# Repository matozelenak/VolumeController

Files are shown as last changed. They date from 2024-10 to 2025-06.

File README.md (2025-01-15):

# Hardvérový ovládač hlasitostí jednotlivých aplikácií bežiacich na PC

## Obsah

- [Softvér](#softvér)
- [3D tlač](#3d-tlač)
- [Zoznam súčiastok](#zoznam-súčiastok)
- [Zapojenie](#zapojenie)
- [Zloženie](#zloženie)
- [Výsledok](#výsledok)

## Softvér

- [Arduino kód](arduino/README.md)
- [Softvér na Windows](windows/README.md)
- [Softvér na Linux](linux/README.md)
- [GUI](gui/README.md)

## 3D tlač

Treba vytlačiť:
- krabičku ([controller_case](3d_models/controller_case.stl))
- predný panel ([controller_front_panel](3d_models/controller_front_panel.stl))
- zadné krytky na ledky (6x) ([led_cover](3d_models/led_cover.stl))
- všetky súbory logo_*.stl (odporúčam tlačiť na veľmi pomalej rýchlosti, cca 10mm/s)
- držiak na Arduino ([nano_holder_v2](3d_models/nano_holder_v2.stl))

Držiak na Arduino Nano pochádza z [Thingiverse](https://www.thingiverse.com/thing:596400).

## Zoznam súčiastok

Všetky súčiastky som kupoval v internetovom obchode [Techfun.sk](https://techfun.sk/).

Zoznam:
- Arduino Nano (zvolil som verziu s USB-C konektorom)
- lineárny potenciometer 10K (6 kusov)
- TTP223 kapacitné dotykové tlačidlo (6 kusov)
- WS2812B led pásik (potrebných len 6 kusov LED, ale najmenšia možná dĺžka, ktorá sa dá kúpiť je 1m, zvolil som variantu 60 led/meter, nevodotesný)
- elektrolitický kondenzátor 330µF 16V (1 kus)
- rezistor 330Ω
- female piny
- krytky na potenciometre
- kábliky
- zmršťovacie trubice (na ochranu spojov)

Ďalšie potrebné veci:
- lepidlo (využíval som hlavne lepiacu pištoľ a sekundové lepidlo)
- skrutky 2.5x8mm (4 kusy) (dĺžka nemusí byť presne 8mm, najdlhšie však 20mm)
- skrutky 2.75x5mm (2 kusy) (na uchytenie Arduino držiaka do krabičky)
- obyčajný papier
- tenký priehľadný plastový obal z produktov (viď obrázok)

Arduino Nano:
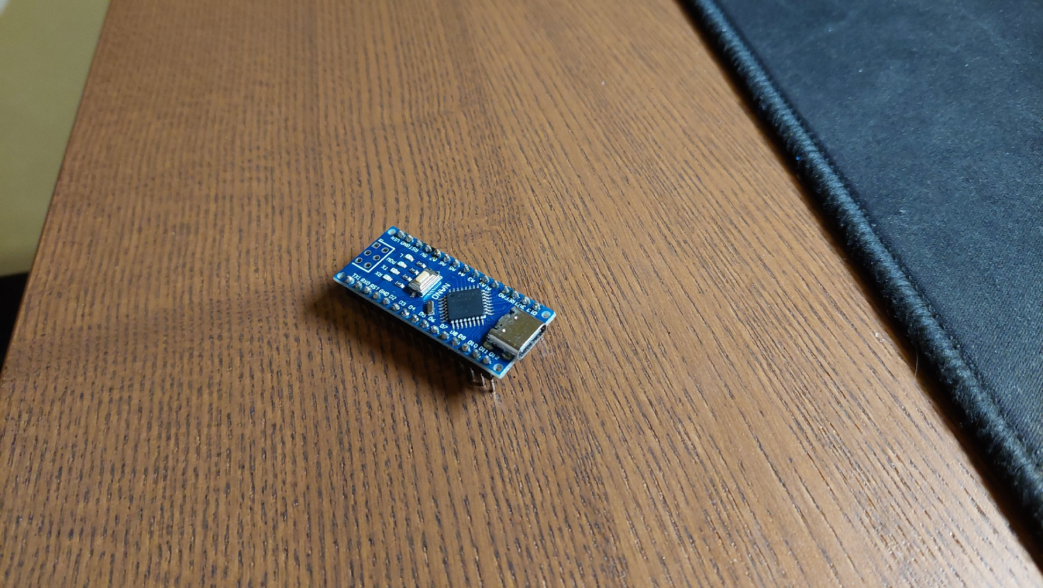
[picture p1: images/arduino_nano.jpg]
Arduino Nano

Potenciometer s krytkou:
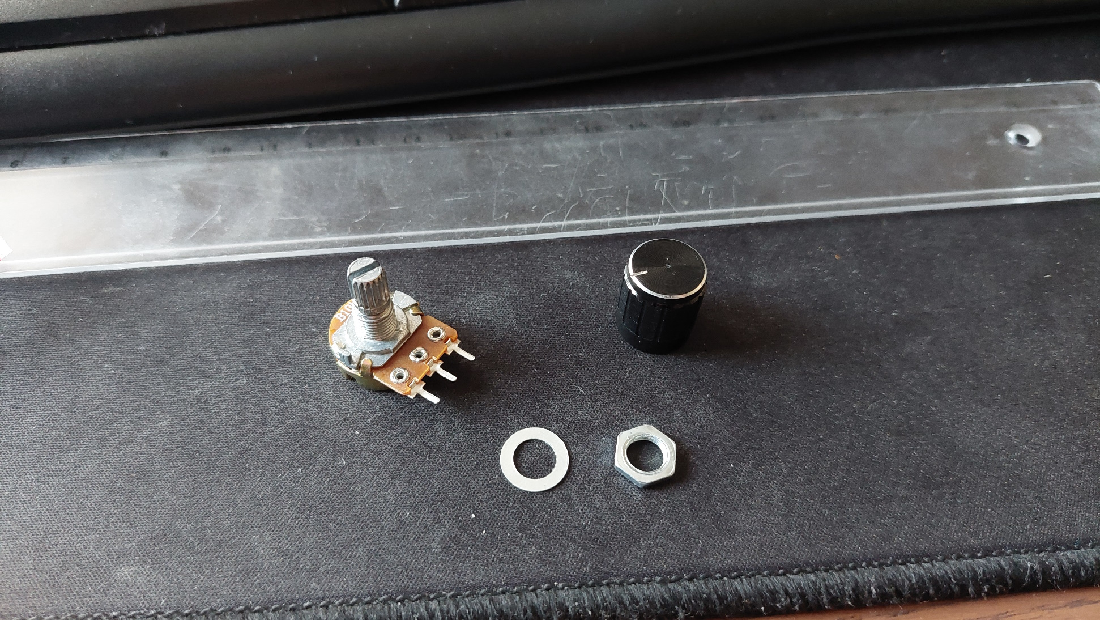
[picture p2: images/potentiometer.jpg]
potenciometer

Kapacitné dotykové tlačidlo TTP223:
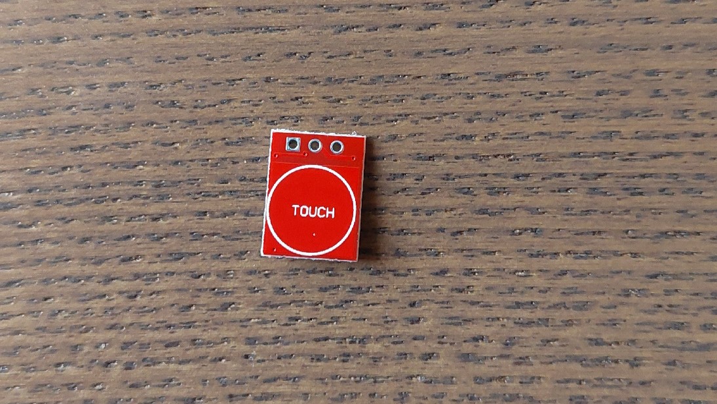
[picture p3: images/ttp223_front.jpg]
ttp223 front

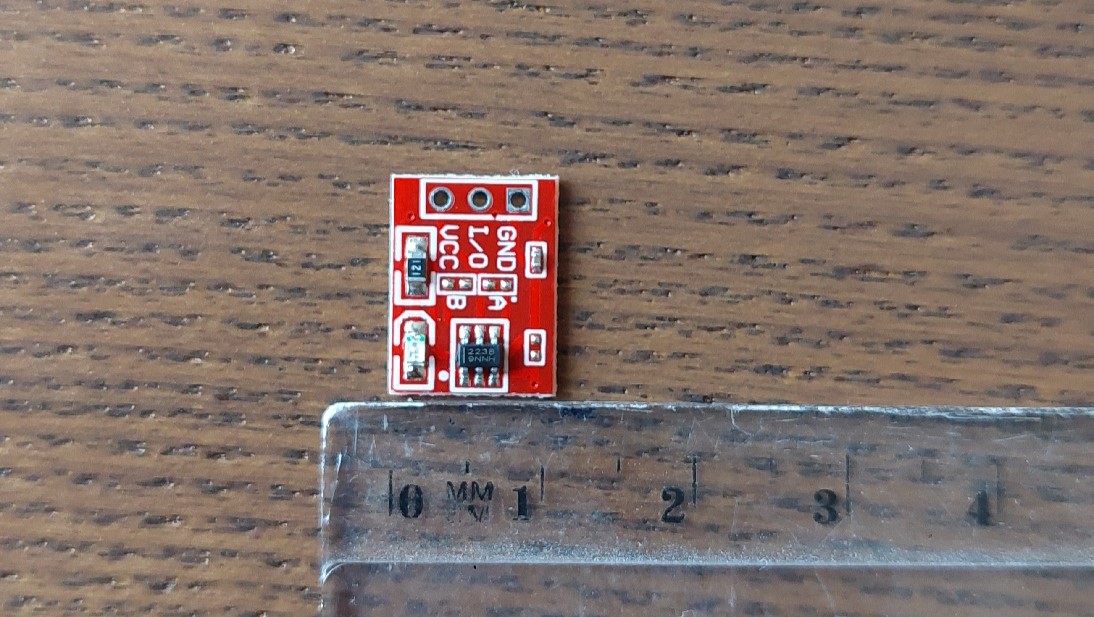
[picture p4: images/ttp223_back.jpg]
ttp223 back

LED pásik WS2812B:
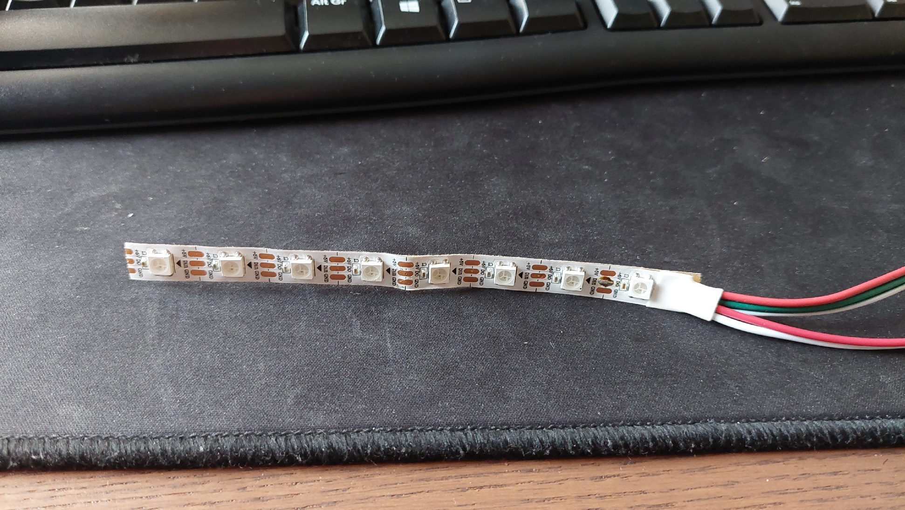
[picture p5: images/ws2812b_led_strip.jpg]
ws2812b

Female piny:
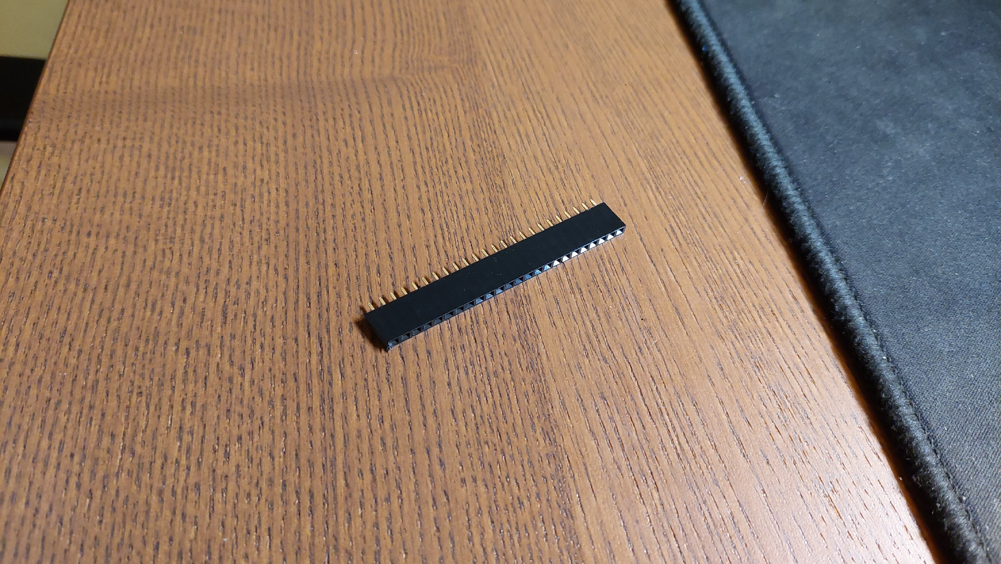
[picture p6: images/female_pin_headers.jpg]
female pin headers

Plastový obal (príklad):
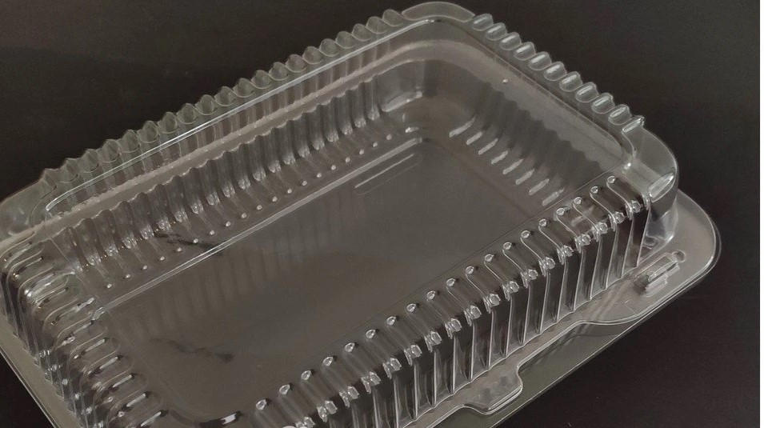
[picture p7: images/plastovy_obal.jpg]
plastovy obal


## Zapojenie

> [!IMPORTANT]
> [Schéma zapojenia](schematic.pdf)

Potenciometre sú zapojené nasledovne: krajné piny sú pripojené na +5V a GND, stredné piny (výstupy) sú pripojené k Arduino analógovým pinom A2-A7. Pri pohľade na potenciometer spredu s pinmi dolu je potrebné na ľavý pin pripojiť GND a na pravý +5V, čo bude mať za následok, že pri úplnom otočení potenciometra vľavo (proti smeru hodinových ručiciek) bude na výstupe 0V. Pri opačnom zapojení +5V a GND a úplnom ľavom otočení by bolo na výstupe 5V, čo by sa však dalo napraviť v softvéri.

Tlačidlá TTP223 sa pripájajú na +5V, GND a ich výstup označený ako 'I/O' sa pripája k Arduinu na digitálne piny podľa schémy.

Pred prvú ledku sa na DIN pripája 330Ω rezistor, je to odporúčanie výrobcu.

## Zloženie

Všetky logá treba nalepiť na kúsok priehľadného plastu, vystrihnutého presne na rozmery priestoru, kam sa vkladá ledka. Tento plast treba následne prilepiť a prekryť kúskom papiera taktiež vystrihnutého na správne rozmery  a prilepiť.
Led pásik treba postrihať na samostatné ledky, ktoré treba nalepiť na led krytku ([led_cover](3d_models/led_cover.stl)). Krytky je následne potrebné prilepiť o predný panel, stačí lepiacou páskou kvôli rozoberateľnosti.

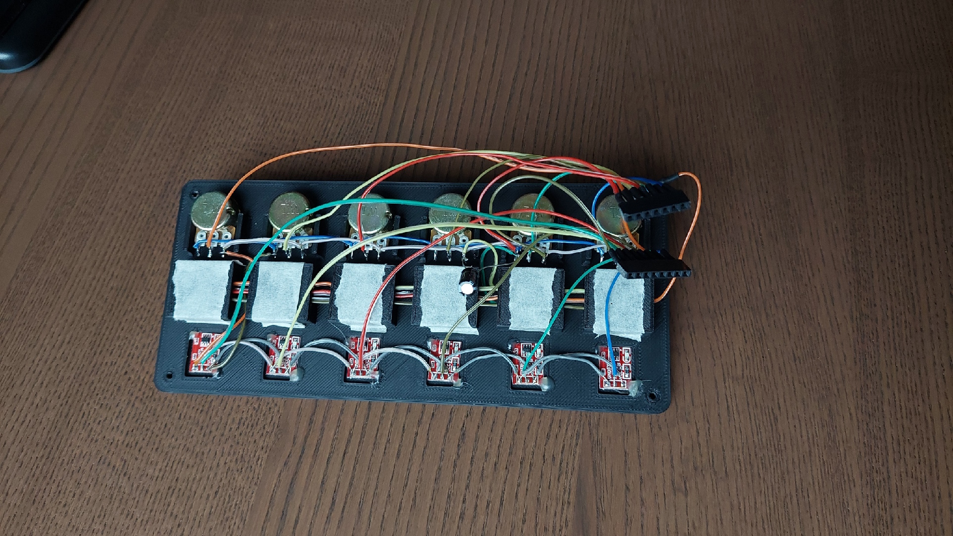
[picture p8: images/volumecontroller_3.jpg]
Vnútorné zapojenie


## Výsledok

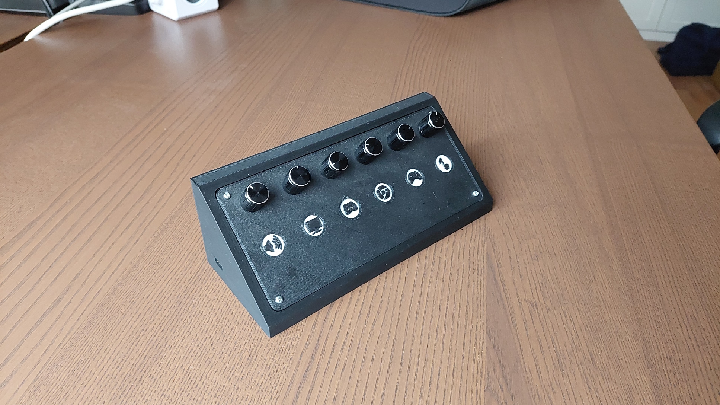
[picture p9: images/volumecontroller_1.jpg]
VolumeController1

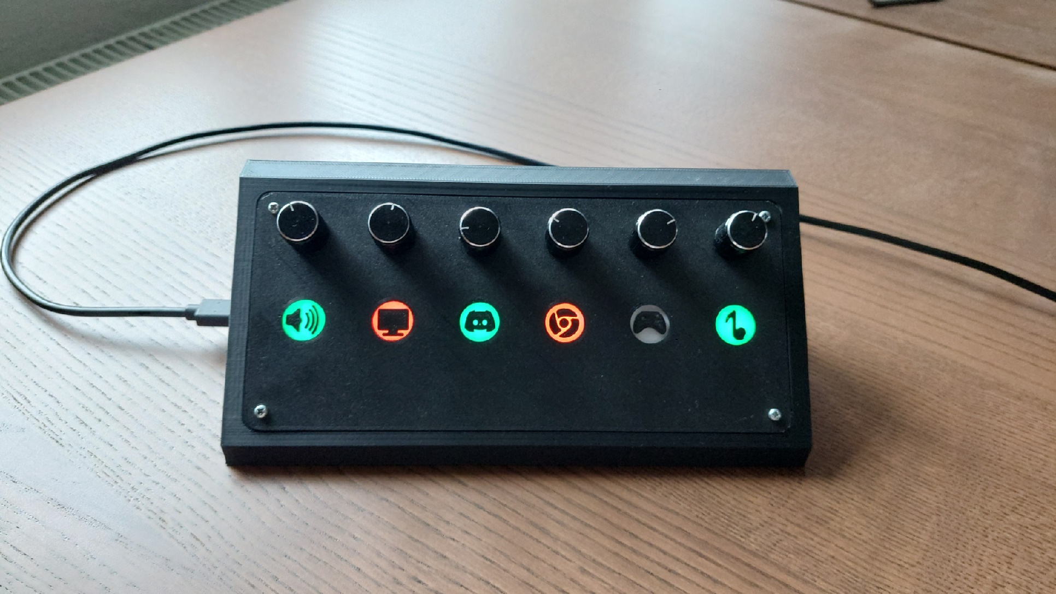
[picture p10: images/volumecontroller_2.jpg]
VolumeController2


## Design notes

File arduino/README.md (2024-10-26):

# Arduino kód

## Kompilácia s PlatformIO v editore VS Code

Stačí vytvoriť nový projekt:
- Board: Arduino Nano ATmega328
- Framework: Arduino
- pridať knižnicu FastLED (v projekte je použitá verzia 3.8.0)
- súbory main.cpp a globals.h umiestniť do priečinka src v projekte
- zvoliť správny COM port (alebo ponechať na Auto) a Uploadnuť program

## Kompilácia v Arduino IDE

- vytvoriť nový Sketch
- prekopírovať obsah súboru main.cpp do Sketch-u (do súboru s príponou .ino)
- do priečinka so Sketch-om pridať súbot globals.h
- nainštalovať knižnicu FastLED cez Library Manager
- zvoliť správny COM port, Board: Arduino Nano a Uploadnuť program

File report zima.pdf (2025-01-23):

Report zo zimného semestra

Hardvér

Ovládač hlasitosti má 6 samostatných kanálov, ktoré sú konfigurovateľné pomocou softvéru, ktorý bol náplňou projektu na zimný semester. Na pripojenie k počítaču slúži USB C konektor. Jadrom ovládača je doska Arduino Nano, ktorá číta hodnoty z potenciometrov a tlačidiel, ovláda LED diódy a riadi komunikáciu s PC cez sériový port. Každý kanál pozostáva z potenciometra, RGB LED indikátora a kapacitného dotykového tlačidla, ktoré je ukryté v prednom paneli. Schému zapojenia som vytvoril v programe KiCad a je dostupná na Github repozitári projektu. Ovládač nevyžaduje externé napájanie, keďže spotreba všetkých LED pri maximálnom zaťažení (biela farba, 100% jas) je približne 6*60mA = 360mA. 3D modely všetkých potrebných súčastí som vytvoril v programe Autodesk Fusion a sú dostupné na Githube projektu. Následne som všetky súčasti vytlačil na 3D tlačiarni.

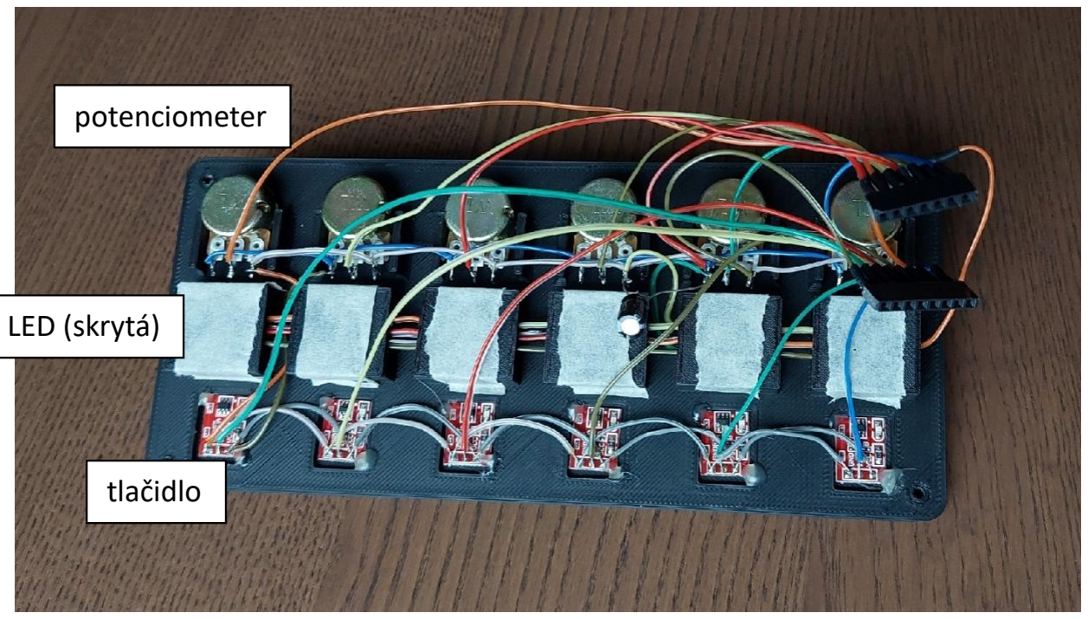
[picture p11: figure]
potenciometer; LED (skrytá); tlačidlo

Obrázok 1: výsledok zapojenia

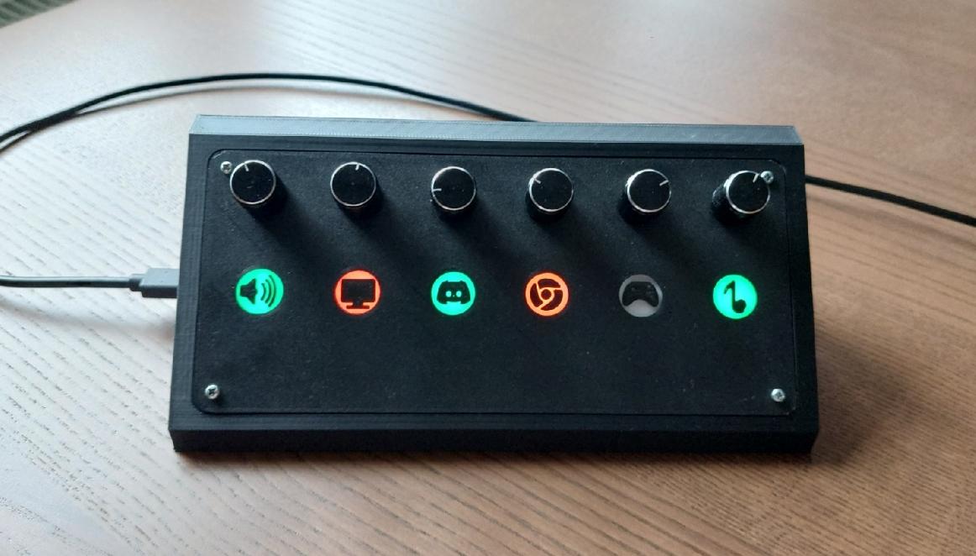
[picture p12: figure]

Obrázok 2: hotový ovládač

Pri písaní Arduino kódu som sa stretol s nasledujúcim problémom: čítanie hodnôt
z potenciometrov pomocou funkcie analogRead() nebolo stabilné, ak v danom momente svietili LED diódy. Zistil som, že tento problém priamo súvisel s danými LED. Tieto LED majú v sebe zabudovaný mikročip, ktorý komunikuje s Arduinom, a riadi jas jednotlivých diód vnútri pomocou metódy PWM (Pulse Width Modulation). Znamená to, že diódy sa veľmi rýchlo (s frekvenciou asi 400Hz) zapínajú a vypínajú, čo spôsobovalo problém s čítaním analógových hodnôt. Vyriešil som to pripájkovaním 330µF kondenzátora ku kladnému a zápornému pólu napájania LED.

Riadenie všetkých LED je možné s pomocou knižnice FastLED. (https://github.com/FastLED/FastLED) Na komunikáciu s PC som vytvoril nasledujúci protokol:

- ?V – žiadosť o zaslanie hlasitostí všetkých kanálov (posiela PC -> Arduino)
- ?M – žiadosť o zaslanie stavu stlmenia (muted, not muted) všetkých kanálov (posiela PC -> Arduino)
- ?A – žiadosť o zaslanie stavu (active, inactive) všetkých kanálov (posiela Arduino -> PC)
- !V3:50 – príkaz: nastav hlasitosť kanála č.3 na 50%
- !V:10|20|30|40|50|60| – príkaz: nastav hlasitosť kanálov (1 - 6) na 10%, 20%, ...
- !M2:1 – príkaz: stlmiť kanál č.2 (posiela Arduino -> PC)

Program na Windows (Backend)

Hlavným cieľom v zimnom semestri bolo naučiť sa pracovať s knižnicou Win32 Core Audio API na ovládanie hlasitostí výstupných zariadení, ako aj jednotlivých aplikácii a programov bežiacich na PC so systémom Windows. Program, ktorý som vytvoril, beží na pozadí a čaká na komunikáciu cez sériový port s Arduinom a spracováva príkazy a požiadavky. Udržiava si zoznam výstupných zariadení spolu s tzv. „Audio Sessions“, čo sú vlastne zvukové výstupy jednotlivých aplikácii. Používateľovi umožňuje nastavenie COM portu, prenosovej rýchlosti, ale hlavne priradenie konkrétnych aplikácii k niektorému zo šiestich kanálov. (V jednom kanáli môže byť priradených viacero aplikácii.) Na interakciu s používateľom program pridáva ikonu na panel úloh, ktorá pri kliknutí pravým tlačidlom zobrazí kontextové menu. Položky v menu :

- „Open settings“ – otvorí okno, kde môže používateľ zmeniť nastavenia ako ktorý sériový port sa používa, alebo namapovať jednotlivé audio sessions ku konkrétnym kanálom,
- „Reconnect“, čiže zavrieť a opätovne otvoriť sériový port v prípade potreby,
- „Rescan audio sessions“ – opätovne zostaviť zoznam všetkých audio sessions a výstupných zariadení a namapovať ich k jednotlivým kanálom,
- „Debug info“ – zobrazí MessageBox,
- „Exit“ – ukončí program bežiaci na pozadí

Program tiež zachytáva rôzne eventy:

- Pripojenie a odpojenie COM zariadenia (na automatické otvorenie sériového portu)
- Vytvorenie novej Audio Session – ak používateľ spustí aplikáciu alebo program, ktorý vydáva zvuk, tak môj program túto session automaticky namapuje do správneho kanála (ak bol nejaký nastavený)
- Zánik nejakej Audio Session – program túto session odstráni zo všetkých priradených kanálov
- Zmena predvoleného výstupného zariadenia – vykoná sa operácia „Rescan Audio Sessions“ popísaná vyššie.

GUI

Ďaľším cieľom v zimnom semestri bolo naučiť sa pracovať s platformou ElectronJS (https://www.electronjs.org/) na vytváranie prenosných UI a vytvoriť grafické rozhranie, v ktorom používateľ bude môcť meniť rôzne nastavenia týkajúce sa COM portu, priradiť jednotlivé výstupné zariadenia a audio sessions na PC k jednému zo šiestich dostupných kanálov, ako aj pozrieť si prehľad o tom, čo je kam priradené a ktoré audio sessions sú práve aktívne. Komunikácia Electron aplikácie s windowsovým programom prebieha cez named pipe vo formáte JSON. GUI si môže od backendu vyžiadať obsah konfiguračného súboru, zoznam výstupných zariadení a audio sessions. Backendu potom posiela zmenené nastavenia. Tlačidlo označené číslom 1 vykoná „refresh“ dát – pošle backendu požiadavku na zaslanie vyššie vymenovaných dát. Tlačidlo 2 otvorí dialógové okno, kde používateľ priraďuje jednotlivé audio sessions a zariadenia ku kanálom. Tlačidlo 3 otvorí dialógové okno, v ktorom je možné meniť nastavenia týkajúce sa COM portu.

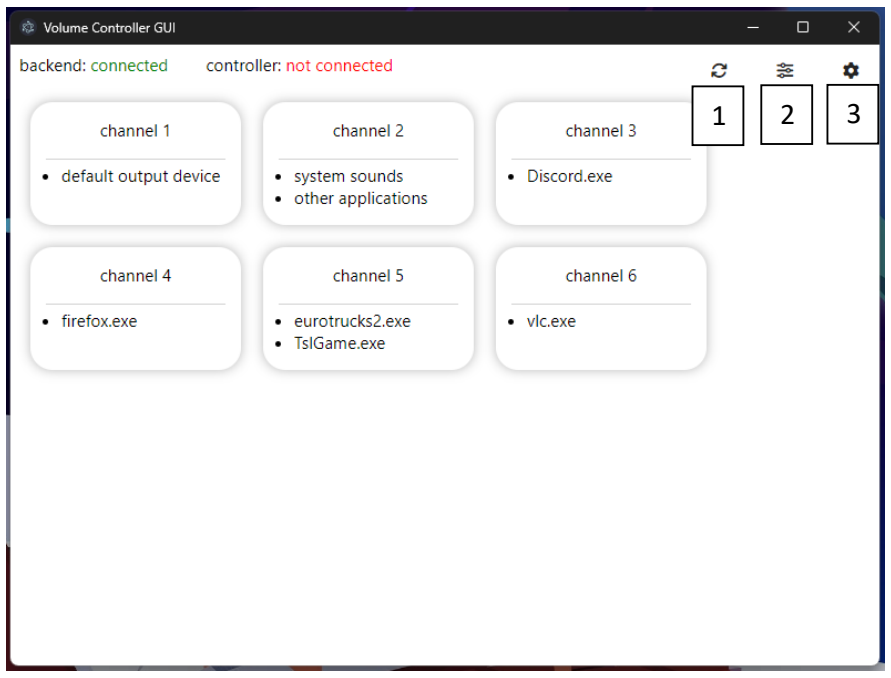
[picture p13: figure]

Obrázok 3: Electron aplikácia

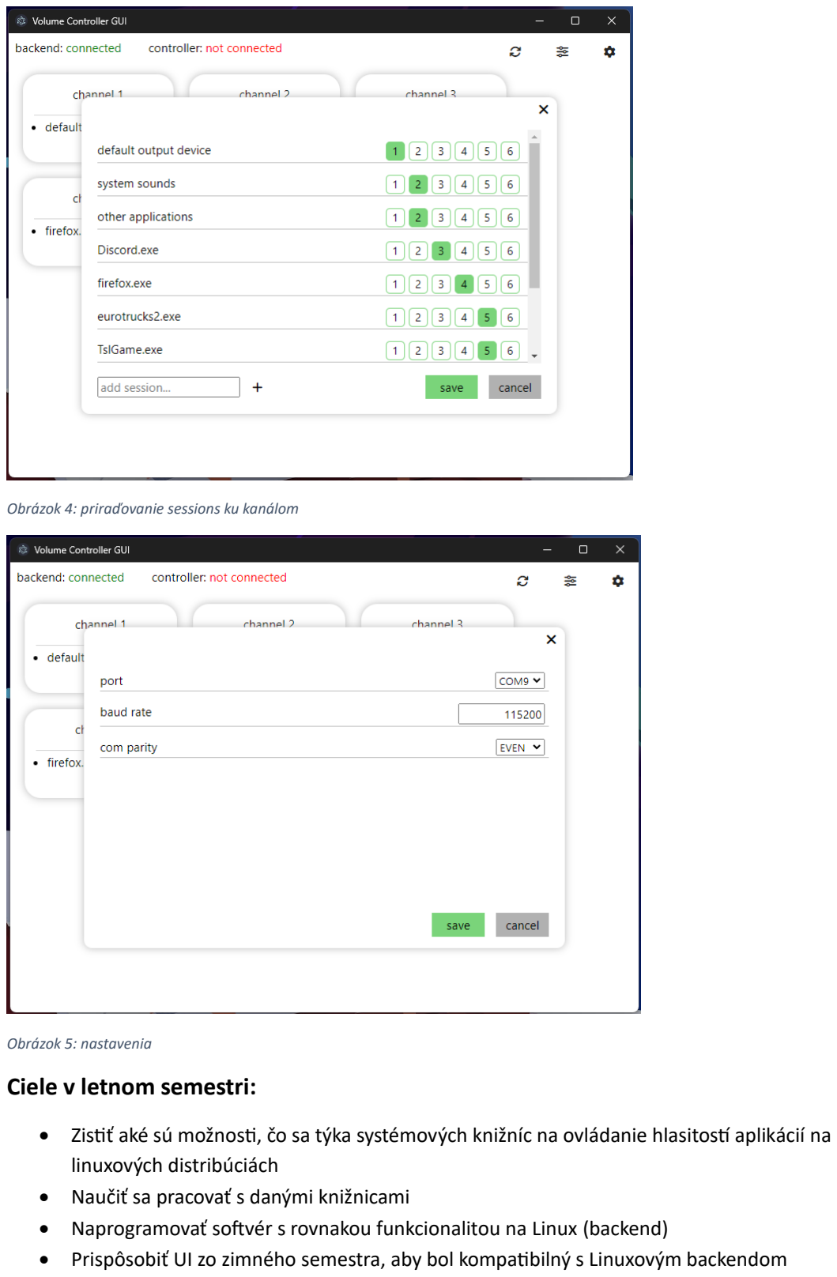
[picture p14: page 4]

Obrázok 4: priraďovanie sessions ku kanálom

Obrázok 5: nastavenia
Ciele v letnom semestri:
- Zistiť aké sú možnosti, čo sa týka systémových knižníc na ovládanie hlasitostí aplikácií na linuxových distribúciách
- Naučiť sa pracovať s danými knižnicami
- Naprogramovať softvér s rovnakou funkcionalitou na Linux (backend)
- Prispôsobiť UI zo zimného semestra, aby bol kompatibilný s Linuxovým backendom

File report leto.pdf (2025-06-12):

## Report z letného semestra

## Úvod

Prvým cieľom v letnom semestri bolo zistiť, ktoré služby a knižnice najčastejšie spravujú audio na linuxových distribúciách. V súčasnej dobe sú to najmä PipeWire, prípadne trochu staršie PulseAudio. Kvôli maximálnej kompatibilite môjho programu s linuxovými distribúciami som sa rozhodol využiť PulseAudio. PipeWire je však spätne kompatibilný aj s PulseAudio.

## PulseAudio

Zoznámil som sa teda s PulseAudio API, ktorá je zdokumentovaná tu. (https://freedesktop.org/software/pulseaudio/doxygen/index.html)
PulseAudio využíva vlastný mainloop na spracovanie eventov, ktorý sa spúšťa volaniami pa_threaded_mainloop_new() a pa_threaded_mainloop_start(). Potom je potrebné vytvoriť a pripojiť tzv. kontext pomocou pa_context_new() a pa_context_connect(). Keďže môj program je multivláknový, je potrebné zavolať pa_threaded_mainloop_lock() pred spustením nejakej operácie a pa_threaded_mainloop_unlock() po ukončení, čím sa zamkne, resp. odomkne mutex. PulseAudio používa nasledovnú terminológiu: sink znamená výstupné zariadenie (napr. reproduktory), sink input je aplikácia, ktorá vydáva zvuk, index je číslo, ktorým je identifikovaný sink alebo sink input.

Prehľad niektorých operácií, ktoré PulseAudio poskytuje:
- pa_context_get_sink_info_list() - získa kompletný zoznam zvukových výstupných zariadení
- pa_context_get_sink_info_by_name() - získa informácie ku konkrétnemu výstupnému zariadeniu
- pa_context_get_sink_input_info_list() - získa kompletný zoznam aplikácií, ktoré prehrávajú nejaký zvuk
- pa_context_set_sink_volume_by_index() - nastaví hlasitosť výstupného zariadenia
- pa_context_set_sink_mute_by_index() - stlmí výstupné zariadenie
- pa_context_set_sink_input_volume() - nastaví hlasitosť aplikácie
- pa_context_set_sink_input_mute() - stlmí aplikáciu

Program na začiatku zistí všetky výstupné zariadenia a aplikácie, ktoré prehrávajú zvuk. Uloží ich do std::map, kde kľúčom je index a hodnotou je štruktúra obsahujúca niekoľko informácií vrátane mena aplikácie, mena výstupného zariadenia, aktuálnej úrovne hlasitosti a pod. Mapa umožňuje vkladanie a vyhľadávanie v logaritmickom čase, čo je výhodné, keďže na manipuláciu so sink a sink input je potrebný index. Index nezačína od nuly, je to prakticky náhodné číslo, ktoré priradí systém.

Program potom načíta konfiguráciu so súboru (ak nejaká existuje) a podľa nej priradí sinks a sink inputs do jedného zo šiestich dostupných kanálov na ovládači. Program tiež sleduje udalosti (events), ktoré vytvára PulseAudio, ako napríklad pridanie nového sink input-u alebo zmena defaultného sink-u a korektne ich spracuje.

IO

Na vykonávanie IO operácií používam v programe samostatné vlákno, ktoré pomocou systémového volania poll() monitoruje niekoľko file deskriptorov. Sú to: sériový port, gui server socket, gui client socket a udev monitor. Na komunikáciu s gui slúži UNIX domain socket (typ AF_UNIX). Jeden socket čaká na pripojenie zo strany gui programu (volanie listen() a accept()). Po pripojení GUI vráti nový socket, ktorý je teda tiež monitorovaný. Posledný file deskriptor predstavuje monitorovanie udalostí o pripojených a odpojených zariadeniach (viac nižšie). Na komunikáciu medzi vláknami som vytvoril dátovú štruktúru - frontu s vlastným mutexom a mechanizmom wait a signal, ktorý poskytuje knižnica pthread.h. Pomocou tejto fronty môžu ostatné vlákna posielať hlavnému vláknu správy, napr. keď prídu dáta na sériový port, na gui socket, alebo keď je pripojené nové USB zariadenie.

## Signály, udev

Na spracovanie signálov (Linux Signals) využívam samostatné vlákno, ktoré čaká na volaní sigwait(). Zachytáva SIGINT a SIGTERM, pri ich zachytení odovzdá hlavnému vláknu informáciu, že má skončiť.
Na sledovanie udalostí spojených s io-zariadeniami na Linuxe slúži knižnica udev. Umožňuje môjmu programu sledovať, či bolo pripojené, resp. odpojené nejaké zariadenie. Program konkrétne sleduje USB tty zariadenia a reaguje na tieto udalosti.

## System-Tray ikony

Ku koncu semestra som zisťoval, aké knižnice umožňujú na Linuxe zobrazenie system-tray ikony. Existuje ich tiež niekoľko v závislosti od konkrétnej distribúcie. Napr. Ubuntu používa knižnicu libayatana-appindicator. Zistil som, ako sa s ňou pracuje a implementoval som aj jednoduché kontextové menu. Nechcel som však aby bol program viazaný na túto konkrétnu knižnicu, preto som sa rozhodol, že jej implementáciu zahrniem do dynamickej knižnice (prípona .so, Shared Object), ktorá bude samostatne skompilovateľná. Hlavný program sa potom pokúsi nájsť túto dynamickú knižnicu a načítať ju. Na toto sa využíva rozhranie dlfcn.h. Poskytuje funkcie dlopen(), dlclose(), dlsym(). Neskôr som sa ešte dozvedel o existencii Qt frameworku, ktorý využívajú hlavne systémy s KDE Plasma, avšak je podporovaný aj prostredím GNOME na Ubuntu. Implementoval som teda aj verziu dynamickej knižnice pomocou tohto frameworku. Používateľ sa vďaka tomu môže rozhodnúť, ktorú verziu skompiluje, prípadne ani jednu, bez toho, aby to ovplyvnilo hlavnú funkcionalitu programu.

## Záver

Podarilo sa mi naplniť všetky ciele na letný semester. Program je funkčný, komunikuje s hardvérom, s GUI, a používateľovi zobrazuje ikonu. Na jednoduchú kompiláciu a inštaláciu som vytvoril makefile a shell skripty. Celý projekt vrátane windows programu a GUI zo zimného semestra, linuxového programu, arduino kódu, ako aj schéma zapojenia a návod na výrobu ovládača, sa nachádza na Githube. (https://github.com/matozelenak/VolumeController)

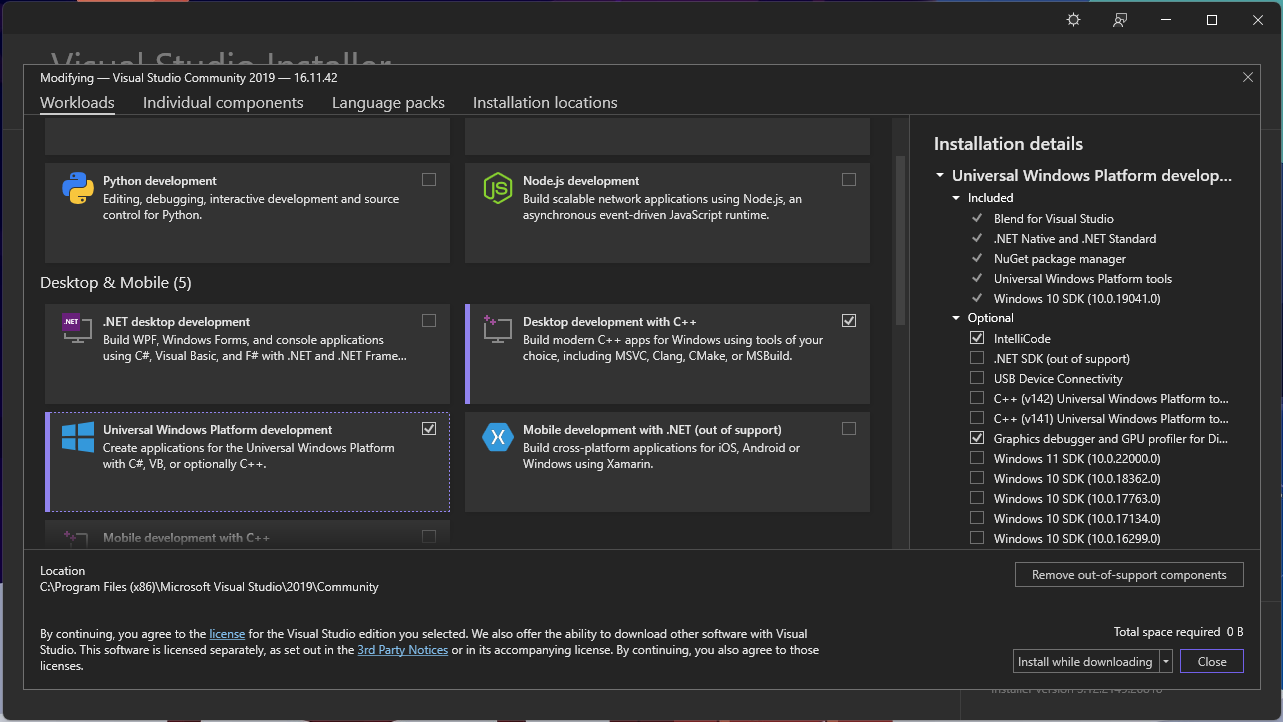
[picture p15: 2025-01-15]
windows/images/vs_workloads.png

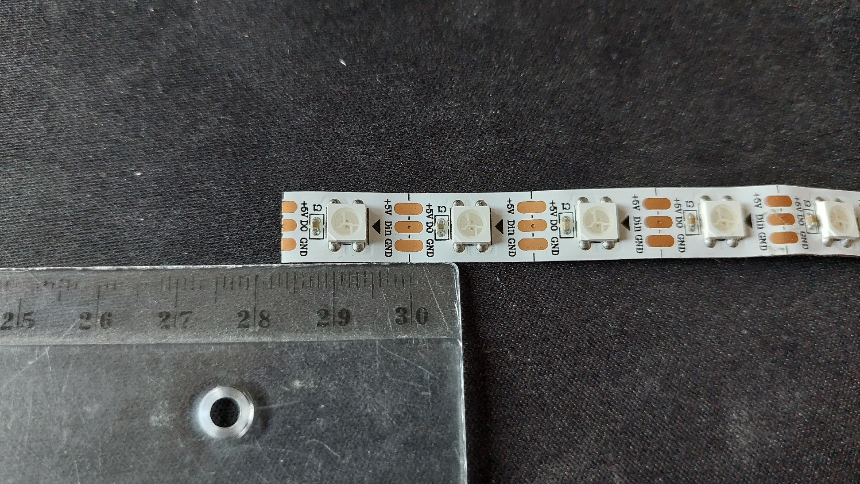
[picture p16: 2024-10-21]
images/ws2812b_led_strip_close.jpg

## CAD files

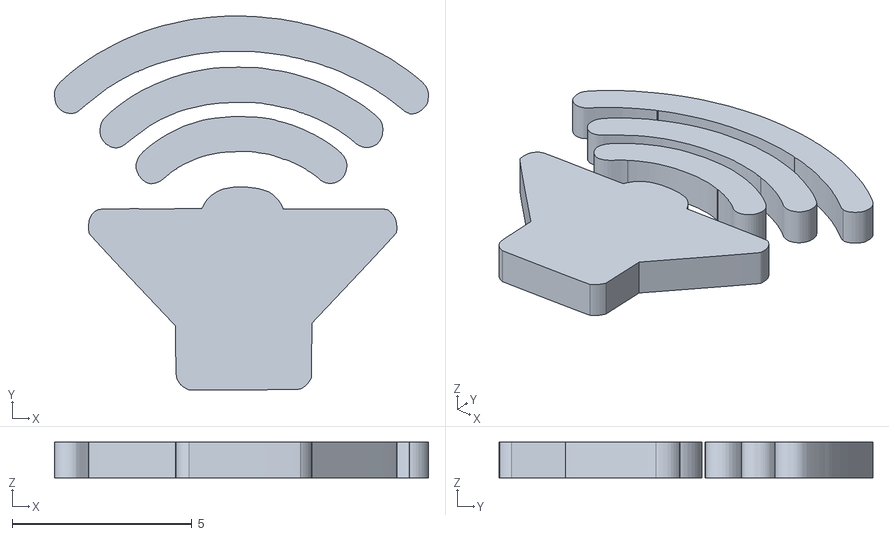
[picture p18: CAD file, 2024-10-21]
3d_models/logo_sound.stl
10.4 x 10.4 x 1.00

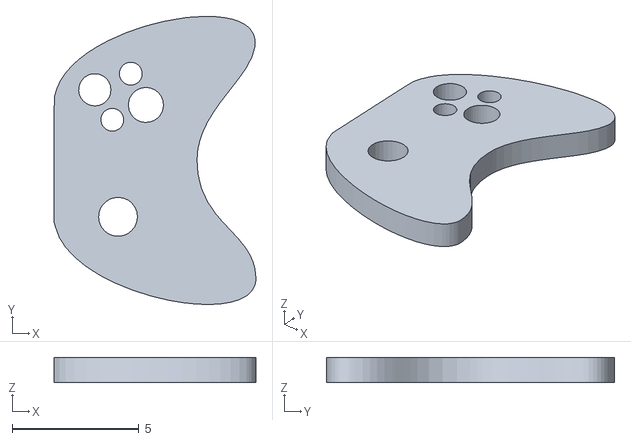
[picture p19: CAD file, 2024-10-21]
3d_models/logo_game.stl
7.96 x 11.4 x 1.00

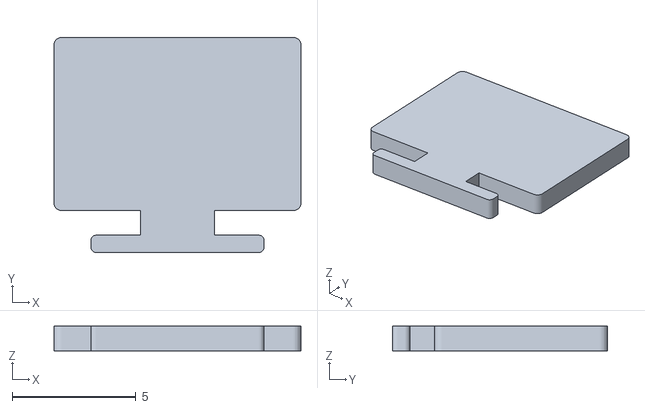
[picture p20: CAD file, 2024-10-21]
3d_models/logo_computer.stl
10.0 x 8.70 x 1.00

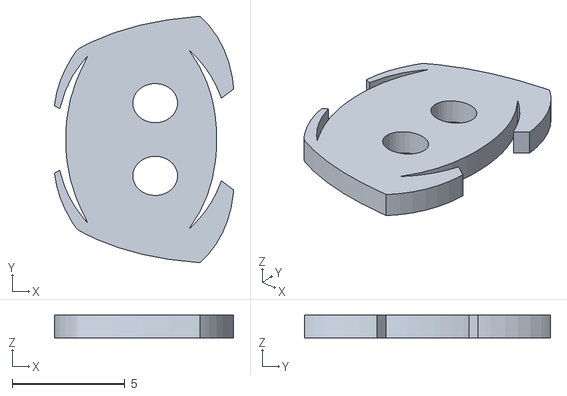
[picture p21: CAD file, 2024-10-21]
3d_models/logo_discord.stl
7.95 x 10.9 x 1.00

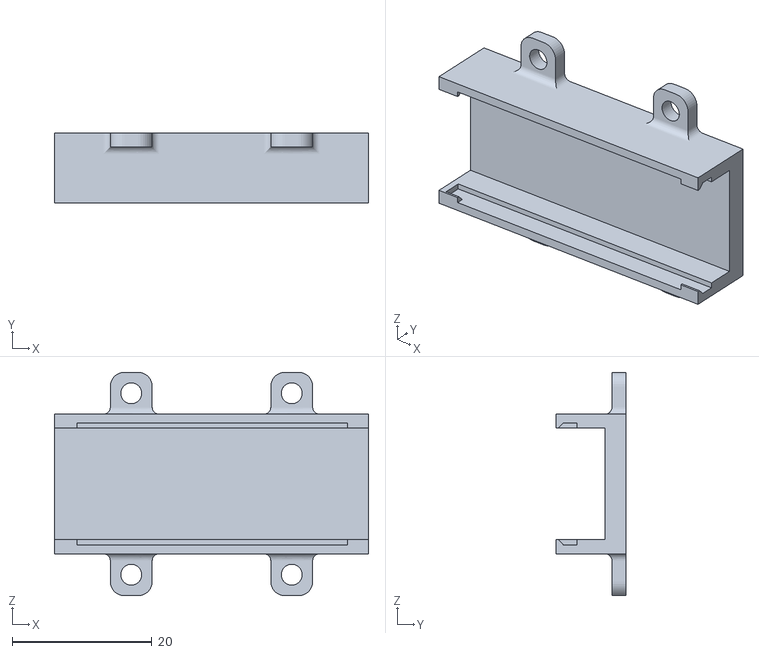
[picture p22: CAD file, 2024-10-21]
3d_models/nano_holder_v2.stl
45.0 x 10.0 x 32.0

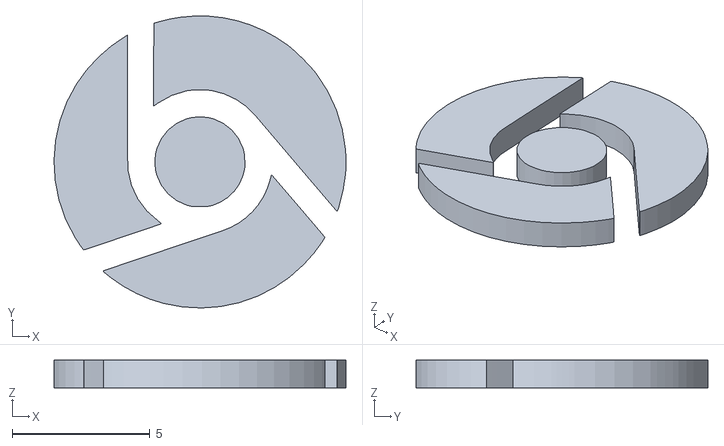
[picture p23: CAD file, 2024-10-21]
3d_models/logo_chrome.stl
10.6 x 10.6 x 1.00

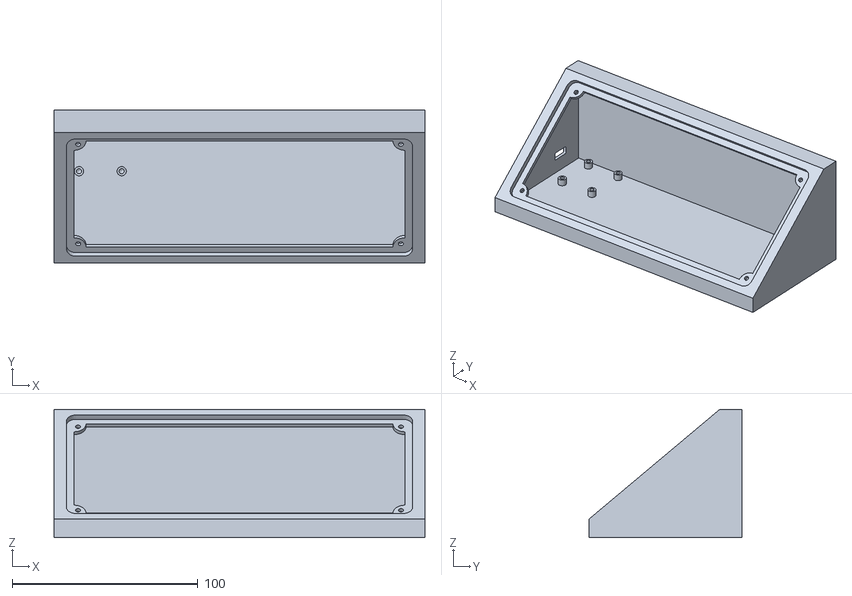
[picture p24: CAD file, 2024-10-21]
3d_models/controller_case.stl
200.0 x 82.5 x 69.1

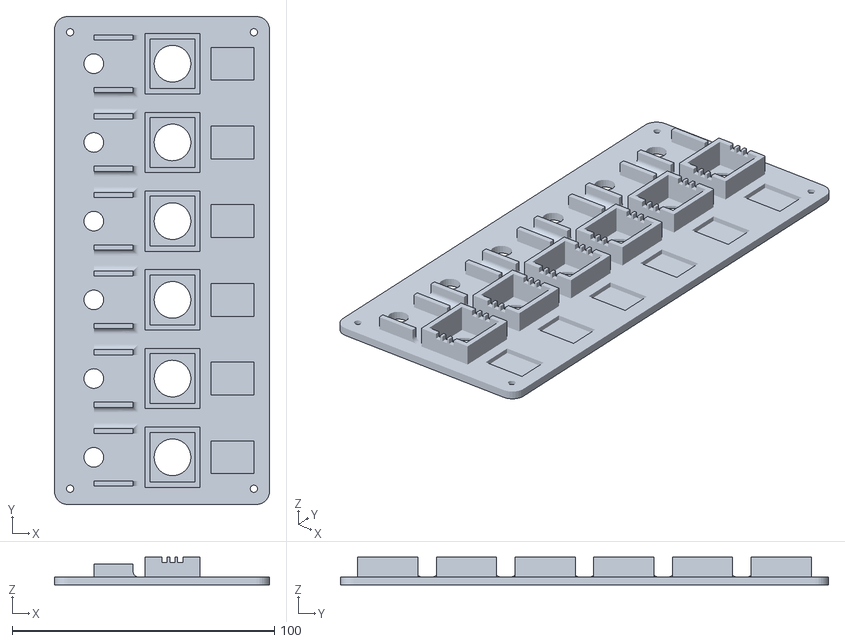
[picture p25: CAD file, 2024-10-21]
3d_models/controller_front_panel.stl
82.0 x 186.0 x 10.5

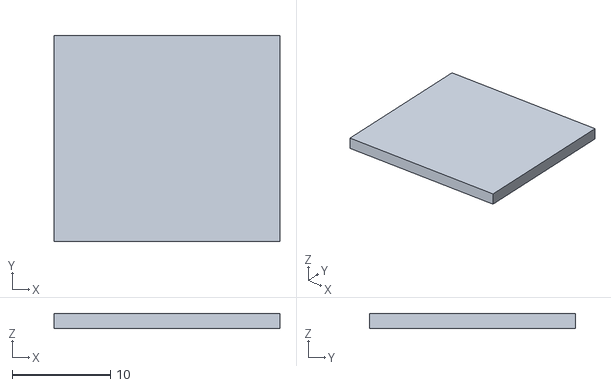
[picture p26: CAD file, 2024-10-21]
3d_models/led_cover.stl
23.0 x 21.0 x 1.50

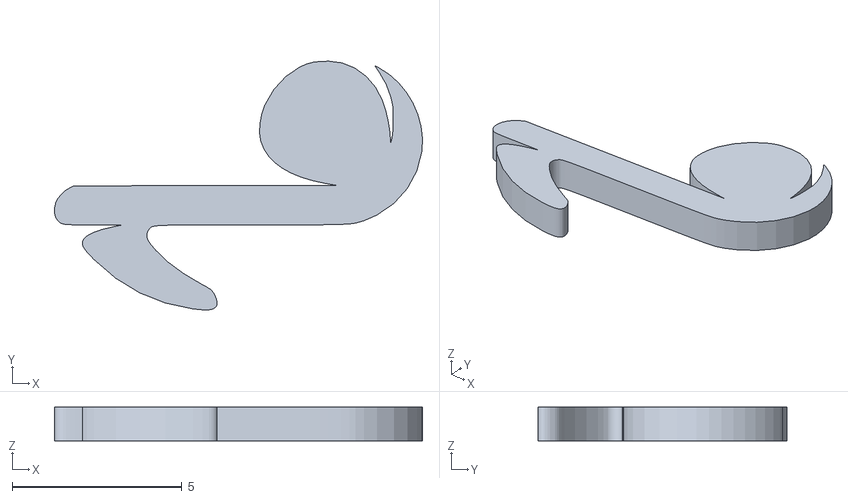
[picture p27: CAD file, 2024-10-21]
3d_models/logo_music.stl
10.8 x 7.32 x 1.00

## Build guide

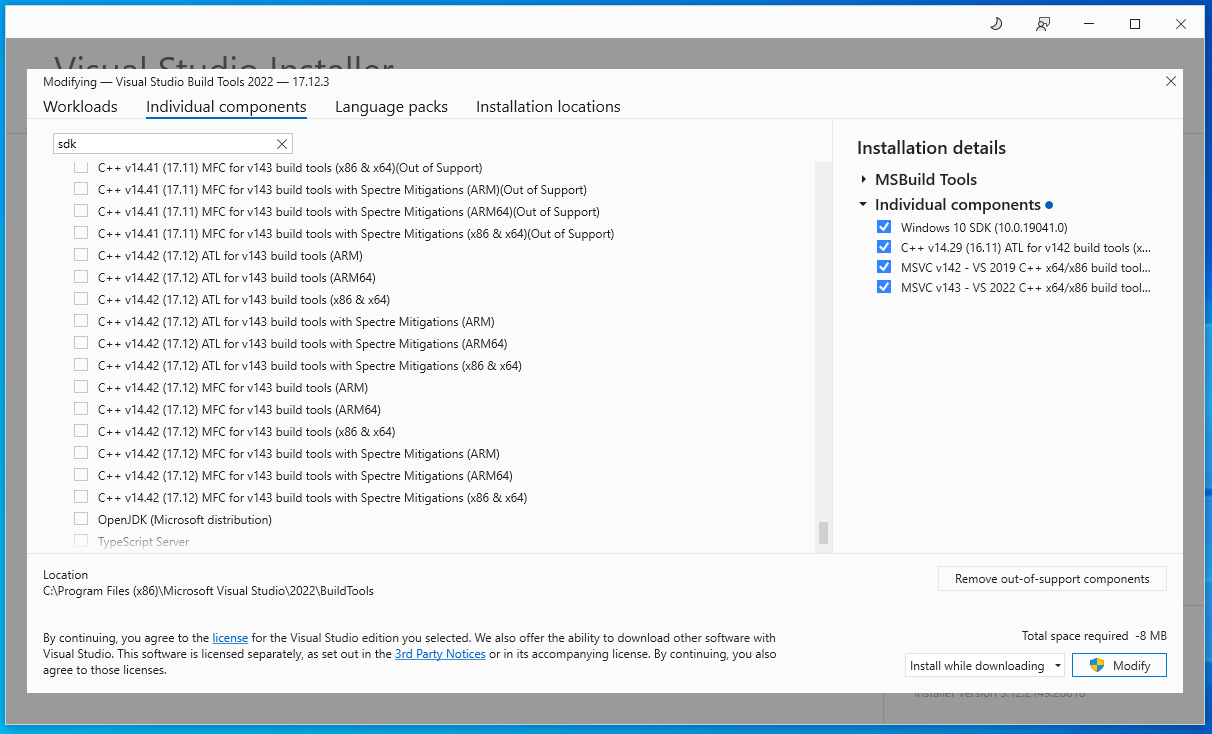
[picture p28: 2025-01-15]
windows/images/buildtools_install.png

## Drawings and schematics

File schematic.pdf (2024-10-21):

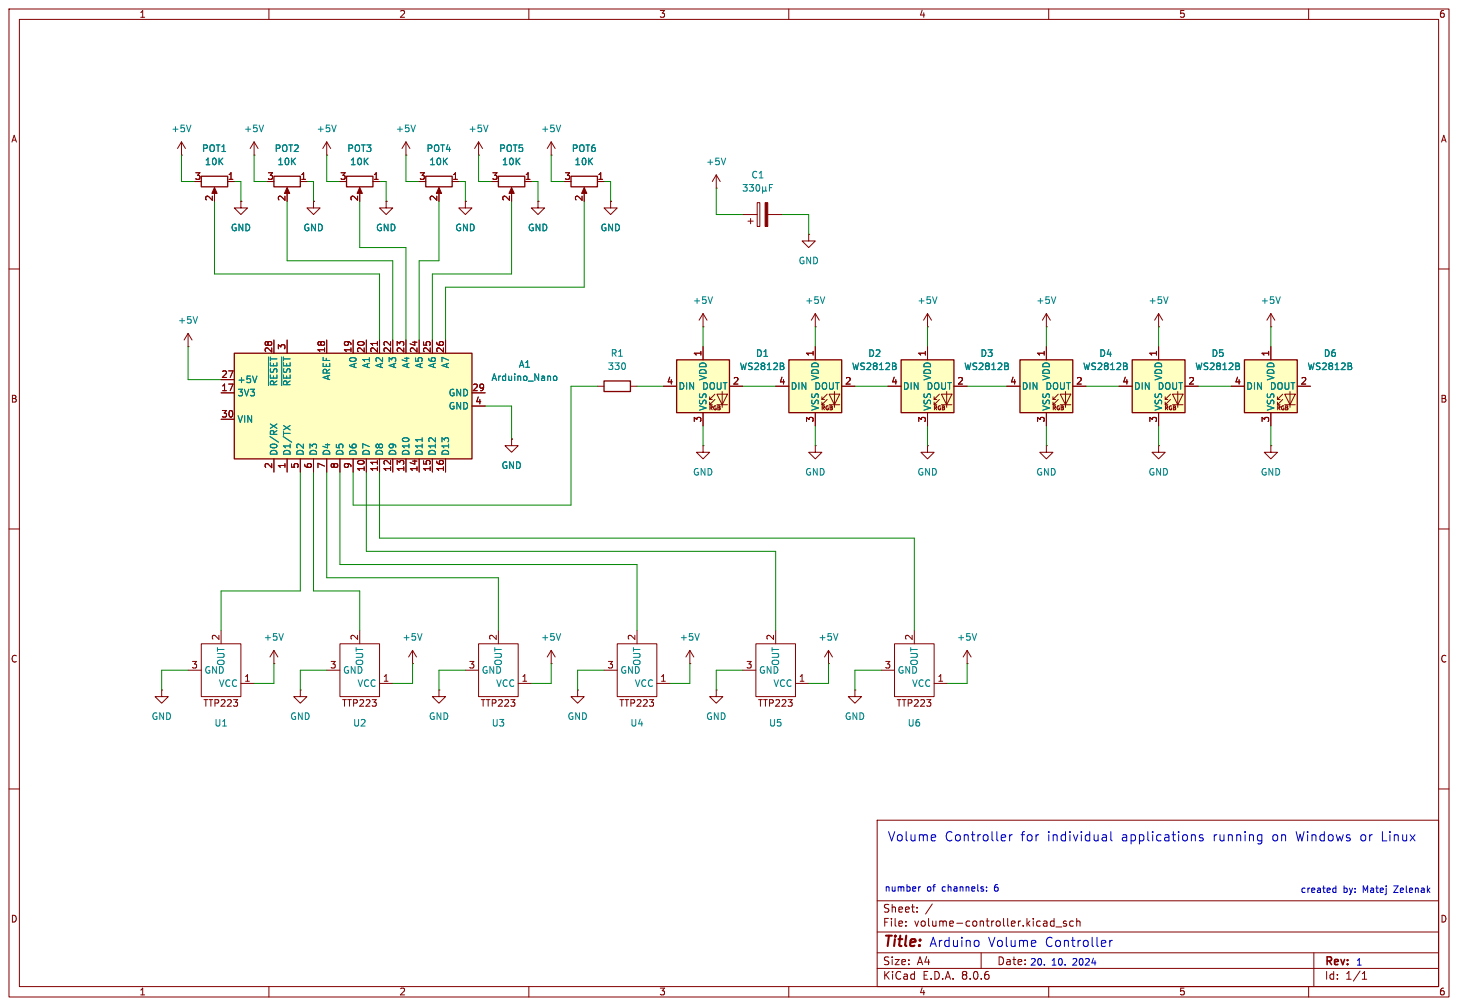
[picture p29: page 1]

2 GND 3 U1 GND GND D1/TX

2 A1 20 A2 21 A3 22 A4 23 A5 24 A6 25 A7 26 +5V 27 ~{RESET} 28 GND 29 ~{RESET}3 VIN 30 GND 4 D2

Id: 1/1 Title: File: volume-controller.kicad_sch Sheet: /

created by: Matej Zelenak Arduino Volume Controller

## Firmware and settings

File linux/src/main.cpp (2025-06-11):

#include "globals.h"
#include <signal.h>
#include <pthread.h>

#include <iostream>
#include <string>
#include <memory>
#include <fstream>
#include <dlfcn.h>
#include <unistd.h>
#include <time.h>
#include "nlohmann/json.hpp"

#include "io.h"
#include "threaded_queue.h"
#include "msg.h"
#include "volume_manager.h"
#include "utils.h"
#include "controller.h"
#include "config.h"
#include "appind_lib.h"

using namespace std;
using json=nlohmann::json;

shared_ptr<IO> io;
shared_ptr<ThreadedQueue<Msg>> msgQueue;
shared_ptr<VolumeManager> mgr;
shared_ptr<Controller> controller;
bool running;
pthread_t thSignal;

const string CONFIG_NAME = "config.json";
const string APPINDLIB_NAME = "appind_lib.so";
const string ICON1_NAME = "vc_icon1.png";
const string ICON2_NAME = "vc_icon2.png";
string APPINDLIB_PATH = APPINDLIB_NAME;
string CONFIG_PATH = CONFIG_NAME;
string ICON1_PATH = ICON1_NAME;
string ICON2_PATH = ICON2_NAME;
Config cfg;

void *hAppIndLib = NULL;
libinit_t ind_libraryInit = NULL; 
seticon_t ind_setIcon = NULL; 
addmenuitem_t ind_addMenuItem = NULL; 
addmenusep_t ind_addMenuSep = NULL; 
showappind_t ind_showAppInd = NULL; 
hideappind_t ind_hideAppInd = NULL; 
destroy_t ind_destroy = NULL;
setclickcb_t ind_setClickCb = NULL; 


void* signalThread(void *param) {
    int sig;
    sigset_t *set = static_cast<sigset_t*>(param);

    while (1) {
        sigwait(set, &sig);
        if (sig == SIGINT || sig == SIGTERM) {
            LOG(sig << " received in signal thread");
            msgQueue->pushAndSignal(Msg{MsgType::EXIT, "stopped by SIGINT"});
            break;
        }
    }

    return NULL;
}

void printSinkInputInfo(int index) {
    Session &session = mgr->getSessionPool()->operator[](index);
    DBG("[SINK INPUT] " << session.name << " " << session.volume << " " << session.muted);
}

void clickCallback(string label, void *data) {
    if (label == "Open GUI") {
        msgQueue->pushAndSignal(Msg{MsgType::CLICK_OPENGUI});
    }
    else if (label == "Rescan sessions") {
        msgQueue->pushAndSignal(Msg{MsgType::CLICK_RESCAN});
    }
    else if (label == "Reconnect") {
        msgQueue->pushAndSignal(Msg{MsgType::CLICK_RECONNECT});
    }
    else if (label == "Exit") {
        msgQueue->pushAndSignal(Msg{MsgType::CLICK_EXIT});
    }
}

int main(int argc, char *argv[]) {
    LOG("Arduino Volume Controller");
    time_t t = time(0);
    cout << ctime(&t);
    LOG("running as: " << argv[0]);
    running = true;

    // create paths
    string path = argv[0];
    int slashPos = path.find_last_of('/');
    if (slashPos != string::npos) {
        path = path.replace(slashPos+1, string::npos, "");
        APPINDLIB_PATH = path + APPINDLIB_NAME;
    }
    char cwd[1024];
    memset(cwd, 0, sizeof(cwd));
    getcwd(cwd, sizeof(cwd));
    string cwdPath = cwd;
    cwdPath += "/";
    CONFIG_PATH = cwdPath + CONFIG_NAME;
    ICON1_PATH = cwdPath + ICON1_NAME;
    ICON2_PATH = cwdPath + ICON2_NAME;
    LOG("cwd: " << cwdPath);
    
    
    // block SIGINT in current thread, new threads should inherit the changes
    sigset_t set;
    sigemptyset(&set);
    sigaddset(&set, SIGINT);
    sigaddset(&set, SIGTERM);
    pthread_sigmask(SIG_BLOCK, &set, NULL);
    pthread_create(&thSignal, NULL, signalThread, &set);

    // load appind_lib if it exists
    hAppIndLib = dlopen(APPINDLIB_PATH.c_str(), RTLD_NOW);
    if (!hAppIndLib) {
        ERR(dlerror());
    } else {
        ind_libraryInit = (libinit_t) dlsym(hAppIndLib, LIBINIT_NAME);
        ind_setIcon = (seticon_t) dlsym(hAppIndLib, SETICON_NAME);
        ind_addMenuItem = (addmenuitem_t) dlsym(hAppIndLib, ADDMENUITEM_NAME);
        ind_addMenuSep = (addmenusep_t) dlsym(hAppIndLib, ADDMENUSEPARATOR_NAME);
        ind_showAppInd = (showappind_t) dlsym(hAppIndLib, SHOWAPPIND_NAME);
        ind_hideAppInd = (hideappind_t) dlsym(hAppIndLib, HIDEAPPIND_NAME);
        ind_destroy = (destroy_t) dlsym(hAppIndLib, DESTROY_NAME);
        ind_setClickCb = (setclickcb_t) dlsym(hAppIndLib, SETCLICKCB_NAME);
    }

    cfg.CONFIG_PATH = CONFIG_PATH;
    Utils::readConfig(cfg);

    msgQueue = make_shared<ThreadedQueue<Msg>>();
    io = make_shared<IO>(msgQueue, cfg);
    mgr = make_shared<VolumeManager>(msgQueue);

    mgr->init();

    if(!io->init()) {
        LOG("failed to initialize IO");
        return 0;
    }
    io->reopenSerialPort();

    controller = make_shared<Controller>(io, mgr, cfg, msgQueue);

    // create app indicator and its menu
    if (hAppIndLib) {
        ind_libraryInit(argc, argv, "VolumeControllerDaemon", ICON1_PATH);
        ind_setIcon(ICON1_PATH);
        ind_addMenuItem("Open GUI", ICON2_PATH);
        ind_addMenuSep();
        ind_addMenuItem("Rescan sessions", "view-refresh-symbolic");
        ind_addMenuItem("Reconnect", "media-eject-symbolic");
        ind_addMenuSep();
        ind_addMenuItem("Exit", "application-exit");
        ind_showAppInd();

        ind_setClickCb(&clickCallback, NULL);
    }

    while (true) {
        msgQueue->lock();
        while (msgQueue->empty()) {
            msgQueue->wait();
        }

        Msg msg = msgQueue->front();
        msgQueue->pop();
        msgQueue->unlock();
        DBG("[MSG] " << (int) msg.type << " data: '" << msg.data << "'");
        switch (msg.type)
        {
        case MsgType::EXIT:
            running = false;
            io->stop();
            goto end_while;

        case MsgType::SERIAL_CONNECTED:
            LOG("[EVENT] serial connect");
            ind_setIcon(ICON2_PATH);
            {
                json data;
                controller->makeStatusJSON(data);
                io->sendPipe(data.dump().c_str());
            }
            break;
        case MsgType::SERIAL_DISCONNECTED:
            LOG("[EVENT] serial disconnect");
            ind_setIcon(ICON1_PATH);
            {
                json data;
                controller->makeStatusJSON(data);
                io->sendPipe(data.dump().c_str());
            }
            break;
        case MsgType::SERIAL_DATA:
            controller->parseData(msg.data);
            break;

        case MsgType::PIPE_CONNECTED:
            LOG("[EVENT] pipe connect");
            break;
        case MsgType::PIPE_DISCONNECTED:
            LOG("[EVENT] pipe disconnect");
            break;
        case MsgType::PIPE_DATA:
            controller->handlePipeData(msg.data);
            break;

        case MsgType::PA_CONTEXT_READY:
            LOG("[EVENT] PA context ready");
            mgr->getDefSinkIdx();
            controller->remapChannels();
            break;
        case MsgType::PA_CONTEXT_DISCONNECTED:
            LOG("[EVENT] PA context disconnect");
            break;

        case MsgType::SINK_ADDED:
            LOG("[EVENT] sink #" << msg.data << " added");
            controller->addDevice(stoi(msg.data));
            break;
        case MsgType::SINK_CHANGED:
            DBG("[EVENT] sink #" << msg.data << " changed");
            break;
        case MsgType::SINK_REMOVED:
            LOG("[EVENT] sink #" << msg.data << " removed");
            controller->removeDevice(stoi(msg.data));
            break;

        case MsgType::SINK_INPUT_ADDED:
            LOG("[EVENT] sink input #" << msg.data << " added");
            printSinkInputInfo(stoi(msg.data));
            controller->addSession(stoi(msg.data));
            break;
        case MsgType::SINK_INPUT_CHANGED:
            DBG("[EVENT] sink input #" << msg.data << " changed");
            printSinkInputInfo(stoi(msg.data));
            break;
        case MsgType::SINK_INPUT_REMOVED:
            LOG("[EVENT] sink input #" << msg.data << " removed");
            controller->removeSession(stoi(msg.data));
            break;

        case MsgType::LIST_SINKS_COMPLETE:
            LOG("[EVENT] list sinks complete");
            break;
        case MsgType::LIST_SINK_INPUTS_COMPLETE:
            LOG("[EVENT] list sink inputs complete");
            break;

        case MsgType::DEFAULT_SINK_CHANGED:
            LOG("[EVENT] default sink changed");
            controller->defaultSinkChanged();
            break;
        case MsgType::DEFAULT_SOURCE_CHANGED:
            LOG("[EVENT] default source changed");
            break;

        case MsgType::CLICK_OPENGUI:
            system("volumecontroller-gui-linux-x64/volumecontroller-gui --no-sandbox &");
            break;
        case MsgType::CLICK_RESCAN:
            controller->remapChannels();
            break;
        case MsgType::CLICK_RECONNECT:
            io->reopenSerialPort();
            break;
        case MsgType::CLICK_EXIT:
            kill(getpid(), SIGTERM);
            break;

        case MsgType::CONFIG_CHANGED:
            LOG("[EVENT] config changed");
            io->configChanged(cfg);
            controller->configChanged(cfg);
            break;
        default:
            break;
        }
        
    }
    end_while: ;


    io->wait();
    mgr->wait();
    pthread_join(thSignal, NULL);
    if (hAppIndLib) {
        ind_destroy();
        dlclose(hAppIndLib);
    }
    LOG("\n\n")

    return 0;
}

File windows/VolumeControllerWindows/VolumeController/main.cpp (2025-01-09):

#include "volume_manager.h"
#include "io.h"
#include "controller.h"
#include "utils.h"
#include "structs.h"
#include "session_notification.h"
#include "globals.h"

#include <iostream>
#include <string>
#include <sstream>
#include <vector>
#include <Windows.h>
#include <shellapi.h>
#include <fstream>
#include <codecvt>
#include <Dbt.h>
#include "json/json.hpp"

#pragma comment(lib, "OneCore.lib")

using json = nlohmann::json;
using namespace std;

const char* CONFIG_FILE = "config.json";

VolumeManager* vol = nullptr;
IO* io = nullptr;
Controller* controller = nullptr;
Config config;

HWND hWnd = NULL;
HMENU hTrayMenu = NULL;
HDEVNOTIFY hDeviceNotify = NULL;
HICON hIconConnected = NULL;
HICON hIconDisconnected = NULL;
NOTIFYICONDATA nid;

void makeStatusJSON(json& doc) {
	doc["status"] = json();
	doc["status"]["deviceConnected"] = io->isSerialConnected();
	ULONG ports[20];
	ULONG count = 20;
	ULONG found;
	GetCommPorts(ports, count, &found);
	doc["status"]["comPorts"] = json::array();
	DBG_PRINT("found " << found << " com ports" << endl);
	for (int i = 0; i < found && i < count; i++) {
		stringstream portName;
		portName << "COM";
		portName << (int)ports[i];
		doc["status"]["comPorts"].push_back(portName.str());
		DBG_PRINT("  found " << portName.str() << endl);
	}
}

void parsePipeMessage(string msg) {
	json doc;
	try {
		doc = json::parse(msg);
	}
	catch (const json::parse_error& e) {
		DBG_PRINT("JSON parse error: " << e.what() << endl);
		return;
	}
	if (doc.contains("request")) {
		json response = json();
		json requests = doc["request"];
		for (string type : requests) {
			if (type == "status") {
				makeStatusJSON(response);
			}
			else if (type == "config") {
				response["configFile"] = Utils::storeConfigToJSON(config);
			}
			else if (type == "sessionPool") {
				json sessionPool = json::array();
				for (PAudioSession& session : vol->getSessionPool()) {
					wstring sessionName = session->getName();
					sessionPool.push_back(Utils::wStrToStr(sessionName));
				}
				response["sessionPool"] = sessionPool;
			}
			else if (type == "devicePool") {
				json devicePool = json::array();
				for (PAudioDevice& device : vol->getDevicePool()) {
					wstring deviceName = device->getName();
					devicePool.push_back(Utils::wStrToStr(deviceName));
				}
				response["devicePool"] = devicePool;
			}
		}
		io->sendPipe(response.dump());
	}
	if (doc.contains("configFile")) {
		// save config
		json cfg = doc["configFile"];
		Utils::parseConfigFromJSON(cfg, config);
		json doc = Utils::storeConfigToJSON(config);
		Utils::writeConfig(doc, CONFIG_FILE);

		io->configChanged();
		controller->rescanAndRemap();
		controller->update();
	}
}

void parseMessage(string msg) {
	if (msg.size() == 0) return;
	if (msg == "READY") {
		// device was just connected
		controller->update();
		return;
	}
	if (msg[0] == '!') {
		// command
		if (msg.size() >= 4) {
			char cmd = msg[1];
			if (msg[2] == ':') {
				// all values
				vector<int> values = Utils::parseCmdAllVals(msg);
				switch (cmd) {
				case 'V':
					for (int i = 0; i < 6; i++) {
						int value = values[i];
						if (value >= 0 && value <= 100) {
							DBG_PRINT("Channel " << i << ": " << value << "%" << endl);
							controller->adjustVolume(i, value);
						}
					}
					break;
				case 'M':
					for (int i = 0; i < 6; i++) {
						int value = values[i];
						if (value >= 0 && value <= 1) {
							DBG_PRINT("Channel " << i << ": " << (value ? "mute" : "unmute") << endl);
							controller->adjustMute(i, value);
						}
					}
					break;
				}
			}
			else {
				// one value
				int chID;
				int value = Utils::parseCmd1Val(msg, chID);
				switch (cmd) {
				case 'V':
					if (chID >= 0 && chID <= 5 && value >= 0 && value <= 100) {
						DBG_PRINT("Channel " << chID << ": " << value << "%" << endl);
						controller->adjustVolume(chID, value);
					}
					break;
				case 'M':
					if (chID >= 0 && chID <= 5 && (value == 0 || value == 1)) {
						DBG_PRINT("Channel " << chID << ": " << (value ? "mute" : "unmute") << endl);
						controller->adjustMute(chID, value ? true : false);
					}
				}
			}
		}
	}
	else if (msg[0] == '?') {
		// request
		if (msg.size() >= 2) {
			char cmd = msg[1];
			switch (cmd) {
			case 'A':
				// channel active data
				io->send(controller->makeActiveDataCmd());
				break;
			case 'M':
				// mute data
				io->send(controller->makeMuteCmd());
				break;
			case 'V':
				// volume data
				io->send(controller->makeVolumeCmd());
			}
		}
	}
}

void registerComDeviceNotification() {
	const GUID GUID_DEVINTERFACE_COMPORT = { 0x86E0D1E0L, 0x8089, 0x11D0, { 0x9C, 0xE4, 0x08, 0x00, 0x3E, 0x30, 0x1F, 0x73 } };

	DEV_BROADCAST_DEVICEINTERFACE NotificationFilter = {};
	NotificationFilter.dbcc_size = sizeof(DEV_BROADCAST_DEVICEINTERFACE);
	NotificationFilter.dbcc_devicetype = DBT_DEVTYP_DEVICEINTERFACE;
	NotificationFilter.dbcc_classguid = GUID_DEVINTERFACE_COMPORT;

	hDeviceNotify = RegisterDeviceNotification(hWnd, &NotificationFilter, DEVICE_NOTIFY_WINDOW_HANDLE);
	if (hDeviceNotify == NULL) {
		DBG_PRINT("Failed to register device notification" << endl);
	}
}

void unregisterComDeviceNotification() {
	if (hDeviceNotify != NULL) {
		UnregisterDeviceNotification(hDeviceNotify);
		hDeviceNotify = NULL;
	}
}

void ShowTrayMenu(HWND hWnd) {
	if (!hTrayMenu) {
		hTrayMenu = CreatePopupMenu();
		AppendMenu(hTrayMenu, MF_STRING, ID_TRAY_OPEN_GUI, L"Open Settings");
		AppendMenu(hTrayMenu, MF_STRING, ID_TRAY_RECONNECT, L"Reconnect");
		AppendMenu(hTrayMenu, MF_STRING, ID_TRAY_RESCAN_SESSIONS, L"Rescan Audio Sessions");
		AppendMenu(hTrayMenu, MF_SEPARATOR, 0, NULL);
		AppendMenu(hTrayMenu, MF_STRING, ID_TRAY_DEBUGINFO, L"Debug info");
		AppendMenu(hTrayMenu, MF_STRING, ID_TRAY_EXIT, L"Exit");
	}

	// show the menu
	POINT pt;
	GetCursorPos(&pt);
	SetForegroundWindow(hWnd);
	TrackPopupMenu(hTrayMenu, TPM_RIGHTBUTTON, pt.x, pt.y-15, 0, hWnd, NULL);
}
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

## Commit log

2024-10-21 added .stl files, images, instructions, schematic
    [controller_case.stl, controller_front_panel.stl, led_cover.stl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]
2024-10-26 added Arduino code
2024-12-01 fix bug in arduino (same value sent multiple times)
    [main.cpp]
2025-03-15 add ThreadedQueue
2025-03-21 update IO to use UNIX socket
2025-03-21 handle SIGINT in signal thread
2025-03-28 list devices
